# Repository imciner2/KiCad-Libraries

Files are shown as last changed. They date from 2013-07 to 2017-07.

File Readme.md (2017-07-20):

# KiCad Libraries

A library containing Kicad schematic symbols, footprints, and project templates.

- - -
## License

<div align="center"><br /></div>

This library is licensed under the Creative Commons BY-SA 4.0 license. The full legal text of the license may be found in the [License](LICENSE.txt) file in this repository. For more information about this license, please visit the Creative Commons Foundation (http://creativecommons.org/licenses/by-sa/4.0/).

- - -
## Using this library

There are 2 ways to use this library: 

1. Copy files locally into project directory (such as by making a Git Subtree)
2. Make a reference to this git repository inside the project (such as by making a Git Submodule)

Both of these methods are discussed in their respective files:

1. [Git Subtrees](UsingGitSubtree.md)
2. [Git Submodules](UsingGitSubmodule.md)

### 3D Parts

In order to view the 3D parts that accompany the footprints, you must add an environment variable called KISYS3DMOD. If it has not been created, this variable points to the location of the preinstalled 3D models. To use these models and the ones in this repo, simply place both paths in the environment variable.

Note: The path should be to the root of the repository, not the 3D directory.

To add this in Linux (and remove existing models), add these two lines to the .bashrc file

```
# Add an environment variable to add the GitHub KiCad 3D models
export KISYS3DMOD='*path/to/github/directory*'
```

### Templates

In order to use the templates contained in this folder, you must add an environment variable called KICAD_PTEMPLATES. This will create a page in the Kicad template selector for "Portable Templates".

Note: Templates must be specified on the end of the environment variable

To add this in Linux, simply add these two lines to the .bashrc file

```
# Add an environment variable to add the GitHub KiCad templates
export KICAD_PTEMPLATES='*path/to/github/directory*/Templates'
```

## Schematic Library Contents

DataStorage - 
 * SD Card
 * uSD Card

Microprocessors - 
 * Sparkfun Atmega 32U4 Breakout Board
 * Microchip PIC18F27J13
 * Microchip PIC32MX340F512H
 * Texas Instruments MSP430G2553 (20, 28, 32 pin versions)

MiscellaneousDevices - 
 * 74LVC1G374  D-type Latch
 * Bridge Rectifier
 * Split Terminal Capacitor
 * LM2937 Voltage Regulator
 * LM317 Voltage Regulator + Heatsink Pin
 * SPDT Relay
 * 3-switch SPST DIP Switch
 * DPDT Switch
 * DPST Switch
 * SPDT Switch
 * SPST Switch
 * Current Transformer
 * Texas Instruments INA333 Instrumentation Amplifier
 * Texas Instruments TS63061 Buck/Boost regulator
 * AC/DC Dual Rail Convertor
 * AC/DC Single Rail Convertor
 * Linear Regulator (Generic symbol for any 3-pin regulator)
 * 18x2 connector
 * Differential Communications Receiver
 * TI DAC5311 8-bit digital-to-analog converter
 * Analog Devices ADA4805-1 low power/shutdown controller operational amplifier
 * TI LM3481 DC/DC low-side NFET converter controller
 * CubeSat Kit 52-pin dual row header
 * Adafruit Feather Board

RF_OEM_Parts - 
 * RFD900
 * SL1204 GPS Antenna
 * Synapse S200
 * Synapse RF300
 * XBee

Sensors - 
 * Analog Devices ADXL345 3-axis Accelerometer
 * Sparkfun Honeywell HMC6352 3-axis magnetometer breakout
 * InvenSense MPU9150 9-dof IMU
 * SkyTraq Venus638 GPS Receiver
 * Antenova M2M M10382 GPS Receiver
 * Honeywell HIH-5030/5031 Humidity Sensor
 * ST Micro LPS331 Pressure Sensor

TransistorParts - 
 * 3-Terminal (GDS) PMOS
 * 3-Terminal (GDS) NMOS
 * NMOST+PMOS in one package
 * NPN+PNP in one package
 * Dual NMOS in one package
 * NMOS with body diode
 * PMOS with body diode

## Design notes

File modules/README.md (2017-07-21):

# KiCad Libraries - Footprint Modules

This directory contains the footprint modules for this KiCad library. All the footprints in this library are designed to be hand-solderable.

The footprints contained in these libraries follow the standards outlined in the master standards file for the repository: [Standards](../LibraryStandards.md)

# Library Listing

* [Batteries](#batteries)
* [Capacitors](#capacitors)
* [Connectors](#connectors)
* [Digilent](#digilent)
* [Diodes](#diodes)
* [Graphics](#graphics)
* [Inductors](#inductors)
* [LEDs](#leds)
* [Modules](#modules)
* [PTH](#pth)
* [Resistors](#resistors)
* [Sensors](#sensors)
* [SMD](#smd)
* [Solarcells](#solarcells)
* [Switches](#switches)
* [Transistors](#transistors)

Note: DK means the digikey part number.

## Batteries:

Footprints for Various battery holders.
 
| Component | Description | More Information |
| --- | --- | ---|
| BATT_BH2AA-PC | 2 AA Battery Holder, Memory Protection Devices | DK: BH2AA-W-ND |
| BATT_CR2032_MPD | CR2032 Holder, Memory Protection Devices | DK: BC2032-F1-ND |
| BATT_CR2032_TE | CR2032 Holder, Tyco Electronics | DK: A99327CT-ND |
 
## Capacitors:

Footprints for various capacitors.

| Component | Description | More Information |
| --- | --- | ---|
| RADIAL_*lead*_*diam* | Thru-hole Radial Capacitors, lead spacing of *lead*, diameter of *diam* | |
| SMD_POL_*package*_*size* | SMD capacitor, package type is *package*, length/width is *size* | |
 
## Connectors:

Footprints for various connectors.

| Component | Description | More Information |
| --- | --- | ---|
| CONN_2.0mm_1x* | Single row 2mm pitch headers (4 pins per row) | |
| CONN_2.54mm_1x* | Single row 0.1in (2.54mm) pitch headers (1-9 pins per row), friction fit capable (offset holes to hold header in with no solder) | |
| CONN_2.54mm_2x* | Double row 0.1in (2.54mm) pitch headers (2-9, 15, 17 pins per row) | |
| DB9_RT_SLIM | Slim fit DB-9 right angle connector | |
| DC_2.1mm_CUI-PJ-202A | DC Barrel Jack, 2.1mm diameter | DK: PJ-202A-ND |
| DEANS | Fullsize Deans plug connector | [Manufacturer](http://wsdeans.com/products/plugs/ultra_plug.html) |
| DEANS_Micro | Micro Deans plug connector | [Manufacturer](http://wsdeans.com/products/plugs/micro_plug.html) |
| DIN_CUI_SD-50BV | 5 pin DIN connector, vertical | DK: CP-3150-ND |
| DIN_CUI_SDS-50J | 5 pin DIN connector, horizontal | DK: CP-2350-ND |
| GAMING_SNES | SNES controller connector | [Manufacturer](http://www.raphnet-tech.com/products/snes_controller_connector/index.php) |
| JST_2.0mm_1x* | JST 2.0mm pitch connectors | |
| MICRO_SD_HINGE_AMP | Hinged uSD card slot | DK: 101-00303-68-1-ND |
| MOLEX_MINI-FIT-JR_3_PTH_RT_PEG | 3 pin right angle thru-hole Molex Mini-Fit Jr connector | |
| MOLEX_MINI-FIT-JR_3_PTH_VERT | 3 pin vertical thru-hole Molex Mini-Fit Jr connector | |
| SAMTEC_TFM-115-01-F-D-A | Samtec 2x15 (30 position) 0.05in (1.27mm) pitch thru-hole header | DK: SAM8700-ND |
| TESTPOINT_063 | Single testpoint, 0.063in hole diameter | |

## Digilent:

Footprints for the board connector specifications proposed by Digilent inc. (such as the PMOD connector).

| Component | Description |
| --- | --- |
| PMOD_DOUBLE_FEMALE | Double row female PMOD connector (0.1in pitch, 2x6) |
| PMOD_DOUBLE_MALE | Double row male PMOD connector (0.1in pitch, 2x6) |
| PMOD_SINGLE_FEMALE | Single row female PMOD connector (0.1in pitch, 1x6) |
| PMOD_SINGLE_MALE | Single row male PMOD connector (0.1in pitch, 1x6) |

## Diodes:

Footprints for various diode packages.

| Component | Description | More Information |
| --- | --- | ---|
| DIODE_DFN1006 | Leadless diode package (1mm x 0.6mm x 0.48mm body) | |
| DIODE_DO214AB-SMC | SMC size surface mount diode package (8.2mm x 6.3mm x 2.7mm body) | |
| DIODE_SOT23-3 | 3-pin SOT23 diode package (Cathode on pin 3, Anode on pin 1) | |

## Graphics:

Various silkscreen graphics for circuit boards.

| Component | Description |
| --- | --- |
| AXIS_Z-DOWN | Axis indicator for a right-handed system with the Z axis going through the board |
| AXIS_Z-UP | Axis indicator for a right-handed system with the Z axis going up from the board |

## Inductors:

Footprints for various inductors.

| Component | Description | More Information |
| --- | --- | ---|
| IND_BOURNS_SRP1238A | Bourns SRP1238A shielded inductor series | [Manufacturer](http://www.bourns.com/docs/Product-Datasheets/srp1238a.pdf) |

## LEDs:

Footprints specifcally for LEDs.

| Component | Description | More Information |
| --- | --- | ---|
| LED_1206 | 1206 Surface Mount LED (1206 footprint with special 3D model) | |

## Modules:

Footprints for various OEM modules.

| Component | Description | More Information |
| --- | --- | ---|
| ADAFRUIT_FEATHER | Adafruit Feather Board | [Manufacturer](https://www.adafruit.com/feather) |
| ESP-12S | ESP8266 WiFI module with integrated antenna | [Datasheet](https://www.elecrow.com/download/ESP-12S_User_Manual.pdf) |
| PS_CUI_VSK-S20 | CUI VSK-20 AC-DC Power Supply, Thru-hole | [Manufacturer](http://www.cui.com/product/resource/vsk-s20.pdf) |
| PS_RECOM_RAC15 | Recom RAC15 AC-DC Power Supply, Thru-hole | [Manufacturer](https://www.recom-power.com/pdf/Powerline-AC-DC/RAC15-S_D_TA.pdf) |
| SYNAPSE_SM200_SMD | Synapse SNAP wireless module, SM200 | [Manufacturer](http://info.synapse-wireless.com/rf-module-sm200pu1) |
| SYNAPSE_PTH | Synapse SNAP wireless module, thru-hole part | |
| XBEE_PTH | Digi XBee wireless module, thru-hole | |
| XBBE_PRO_PTH | Digi XBee-Pro wireless module, thru-hole | |

## PTH:

Footprints for various thru-hole devices.

| Component | Description | More Information |
| --- | --- | ---|
| TO220_HORIZ | TO-220 Package, horizontal mount with screw mount hole | |

## Resistors:

Footprints for resistors.

| Component | Description | More Information |
| --- | --- | ---|
| RES_D2PACK | D2pack resistor footprint | |

## Sensors:

Footprints for various sensors.

| Component | Description | More Information |
| --- | --- | ---|
| ANTENOVA_M10382 | Antenova M10382 GPS Receiver | [Manufacturer](http://www.antenova-m2m.com/wp-content/uploads/2015/11/M10382_11MD-0043-5-PS.pdf) |
| HONEYWELL_HIH_5030 | Honeywell HIH 5030 Humidity Sensor | [Manufacturer](https://sensing.honeywell.com/index.php?ci_id=49692) |
| SHARP_GP1A57HRJ00F | Sharp GP1A57HRJ00F Photo Interrupter | 425-1935-5-ND |

## SMD:

Footprints for various SMD components not in other libraries.

| Component | Description | More Information |
| --- | --- | ---|
| D2PACK | D2Pack | |
| HC-49SM | HC-49SM crystal | |
| LGA_* | LGA footprints, named using the library naming convention | |
| SMD_0805-SPLIT | 0805 component with a split pad (will br bridged when a component is soldered to it) | |
| SMD_0805_FOURPOST | 0805 component with 4 pads (one on each corner) | Fits the [ATB Baluns](https://product.tdk.com/info/en/documents/data_sheet/rf_balun_atb2012_en.pdf) |
| SMD_0805 | 0805 passive device pad | |
| SMD_1206 | 1206 passive device pad | |
| SMD_2010 | 2010 passive device pad | |
| SOIC_* | SOIC (Small Outline Integrated Circuit) footprints, named using the library naming convention | |
| SON_* | SON (Small Outline No-Lead) footprints, named using the library naming convention | |
| SOT_* | SOT (Small Outline Transistor) footprints (3, 5, 6 pins) | |
| SSOP_* | SSOP (Shrink Small Outline Package) footprints, named using the library naming convention | |

## Solarcells:

Footprints for various solarcells.

| Component | Description | More Information |
| --- | --- | ---|
| SPECTROLAB_CIC_26.62 | Spectrolab CIC cell | [Manufacturer](http://www.spectrolab.com/cic.htm) |
| SPECTROLAB_TASC1 | Spectrolab TASC cell, direction 1 (discontinued) | [Manufacturer](http://www.spectrolab.com/DataSheets/PV/PV_NM_TASC_ITJ.pdf) |
| SPECTROLAB_TASC2 | Spectrolab TASC cell, direction 2 (discontinued) | [Manufacturer](http://www.spectrolab.com/DataSheets/PV/PV_NM_TASC_ITJ.pdf) |

## Switches:

Footprints for various switches.

| Component | Description | More Information |
| --- | --- | ---|
| DIP_3_CK_SDA03H0SBD_SMD | 3 position SMD DIP switch | DK: CKN6060-ND |
| DPDT_ESWITCH_EG2207 | DPDT switch, Eswitch EG2207 | DK: EG1940-ND |
| DPST_TE_SSJ12R04 | DPST switch, TE SSJ12R04 | DK: 450-1635-ND |

## Transistors:

| Component | Description | More Information |
| --- | --- | ---|
| TRANS_SOT-23-3_BEC | 3-pin SOT23 package (Base on pin 1, Emitter on pin 2, Collector on pin 3) | |
| TRANS_SOT-23-3_GSD | 3-pin SOT23 package (Gate on pin 1, Source on pin 2, Drain on pin 3) | |
| TRANS_SO_4.0mm_1.27mm_8 | 8-pin SO package (Gate on pin 4, Source on pins 1-3, Drain on pins 5-8) | |

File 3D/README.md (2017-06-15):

# KiCad Libraries

## Creating 3D Components

To create a new 3D component:

Using OpenSCAD (Based on http://happyrobotlabs.com/posts/tutorials/tutorial-3d-kicad-parts-using-openscad-and-wings3d/):
1) Create the part in OpenSCAD
2) Compile it, then export as a .stl
3) Run meshconv on the file:
    ./meshconv -c stl Path/To/Part-scad.stl -o Path/To/Part-wings
4) Import the new .stl into Wings3D and do the material changing
5) Export as a .wrl file
6) Copy the .wrl file into the 3D folder from its source folder

## 3D Part Models

Batteries:
 * Memory Protection Devices CR2032 Holder (Digikey #: BC2032-F1-ND)

Connectors:
 * 1x6 0.1" female right angle
 * 2x6 0.1" female right angle
 * 1x6 0.1" male right angle
 * 1x6 0.1" male right angle
 * 2.1mm DC Barrel jack (CUI PJ-202A)
 * Deans Plug
 * Micro Deans Plug
 * DIN - Vertical - CUI SD-50BV
 * DIN - Right Angle - CUI SDS-50J 
 * SNES Controller
 * Molex MiniFit Jr 3 pin right angle
 * Samtec 2x15 Thru-hole TFM-115-01-F-D-A
 * uSD card slot - Amphenol (Digikey #: 101-00303-68-1-ND)
 * Testpoint

LEDs:
 * 1206 Surface Mount

Sensors:
 * Sharp GP1A57HRJ00F Photo Interrupter
 * Antenova M2M M10382 GPS Module

SMD:
 * D2PACK
 * 0805
 * 1206
 * 2010
 * HC-49 Surface Mount Crystal
 * No Lead - 3.15mm x 3.15mm x 0.80mm
 * No Lead - 3.00mm x 5.00mm x 1.00mm
 * No Lead - 4.00mm x 4.00mm x 1.00mm
 * No Lead - 10.0mm x 10.0mm x 1.29mm
 * SOIC 8  - 4.0mm x 5.0mm - Pitch: 1.27mm
 * SOIC 8  - 4.0mm x 5.8mm  - Pitch: 1.27mm
 * SOT-23-3
 * SOT-23-5
 * SOT-23-6
 * SOT-363
 * SSOP 8  - 3.0mm x 2.0mm - Pitch: 0.50mm
 * SSOP 8  - 3.0mm x 3.0mm - Pitch: 0.65mm
 * SSOP 20 - 4.5mm x 6.6mm - Pitch: 0.65mm

Solarcells:
 * Solarcells - Spectrolab TASC1
 * Solarcells - Spectrolab TASC2
 * Solarcells - Spectrolab 26.62 sq-cm CIC

Switches:
 * DIP - SMD - 3 position - CK SDA03H0SBD (Digikey #: CKN6060-ND)
 * DPST - Eswitch EG2207 (Digikey #: EG1940-ND)
 * DPST - TE SSJ12R04 (Digikey #: 450-1635-ND)

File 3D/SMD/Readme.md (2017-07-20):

No Lead Packages:

*length*\_*width*\_*height*

SOIC:

*length*\_*width*\_*height*\_P*pitch*

SSOP:

*length*\_*width*\_*height*\_P*pitch*

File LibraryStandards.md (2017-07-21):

# Library Standards

* [Schematic Symbol Standards](#schematic-symbol-standards)
  * [Text](#text)
  * [Pins](#text)
* [Footprint Standards](#footprint-standards)
  * [Pad Design](#pad-design)
  * [Text](#text-1)
  * [Naming Convention](#naming-convention)

----------------------------------------------------------------------------

# Schematic Symbol Standards

## Text

| Text Width | Text Height |
| --- | --- |
| 0.040 in | 0.040 in |

## Pins

The length of a pin should be 0.100 in.

----------------------------------------------------------------------------

# Footprint Standards

## Pad Design

For PTH parts:
* Pad 1 should be a square pad, all others should be round unless required
* Annular ring size should be 1.778mm (0.007in)

## Text

The text fields that should be included on the part are:
* Reference is on Front Silk Screen and is visible, starting value of REF**
* Value is on Front Silk Screen and is invisible, starting value of the footprint name

All text should have the following properties

| Width  | Height | Thickness | 
| --- | --- | --- |
| 1mm | 1mm | 0.2mm |

## Naming Convention

Note: Every field is separated by an underscore.

### Generic Connectors:

| Field | Text |
| ----- | --- |
| 1 | CONN |
| 2 | Pin spacing (in mm) |
| 3 | Number of rows & pins in a row (ie rows x num in rows) |

Example: CONN_2.54mm_1x4

### Specific Connectors:

| Field | Text |
| ----- | --- |
| 1 | Connector Type (optional)  |
| 2 | Manufacturer's Name |
| 3 | Manufacturer's part number |

Example (with type): DC_2.1mm_CUI-PJ-202A

Example (no type)  : SAMTEC_TFM-115-01-F-D-A

### Surface mount components:

| Field | Text |
| ----- | --- |
| 1 | Chip's pacakge label |
| 2 | Total number of pins on the chip |
| 3 | Width of the chip (the plastic casing)  |
| 4 | Length of the chip (the plastic casing) |
| 5 | Pitch of the pins |
| 6 | Additional notation about the package |

Example: SSOP_20_4.5mm_6.6mm_0.65mm_PWP

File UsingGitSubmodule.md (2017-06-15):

# Using Git Submodule to Clone the Library

## Adding to the project (the 1st time)

1. Decide which directory will get the libraries (such as a directory called libraries)

2. Execute the following command (replacing libraries at the end with the desired directory from step 1):

    ``` git submodule add https://github.com/imciner2/KiCad-Libraries libraries ```

3. Interact with the libaries as if it is its own Git repository (aka. pull, commit, push, etc.).

## Updating libraries on fresh clone of KiCad Project

When you first clone a KiCad repository with a submodule of the library, it will not clone the libraries. In order to clone the libraries you must:

1. Initialize the submodules

    ``` git submodule init ```

2. Clone the submodules

    ``` git submodule update ```

This may not always put you on a branch in the server's repository (it may leave you on a floating head branch). To get back to a branch you can make changes to and push to the master, run this inside the submodule:

``` git checkout master ```

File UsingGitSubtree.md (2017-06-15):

# Using Git Subtrees to Clone the Library

## To get the contents of this library into a project git repository

1. Add the remote link:

    ``` git remote add libraries https://github.com/imciner2/KiCad-Libraries.git ```

2. Get the current libraries:

    ``` git fetch libraries ```

3. Initially add the libraries to a project:

    ``` git read-tree --prefix=2-Hardware/libraries -u libraries/master ```

4. Commit the libraries into the repository:

    ``` git commit -m "Kicad libraries initial commit" ```

- - -
## To read in any changes from remote into the project repository:

1. Fetch the libraries repository (if an error occurs running this command, add the remote library again)

    ``` git fetch libraries ```

2. Merge the changes

    ``` git merge -s subtree --squash libraries/master ```

3. Commit the changes

    ``` git commit -m "Updated libraries directory" ```

- - -
## To update the remote with any component changes from this project repository:

1. Create commits for the changes (make them seperate from everything else)

2. Fetch the libraries repository (if an error occurs running this command, add the remote library again)

    ``` git fetch libraries ```

3. Create a new branch locally

    ``` git checkout -b library-work libraries/master ```

4. Add the commits to the desired commits to the new branch (The command shown below will use the 5th commit before the current revision, simply modify the 5 to change which commit is referenced).

    ``` git cherry-pick -x --strategy=subtree master~5 ```

5. Push the changes back to the library master

    ``` git push libraries library-work:master ```

6. Change back to the project repository

    ``` git checkout master ```

7. Delete the working branch

    ``` git branch -D library-work ```

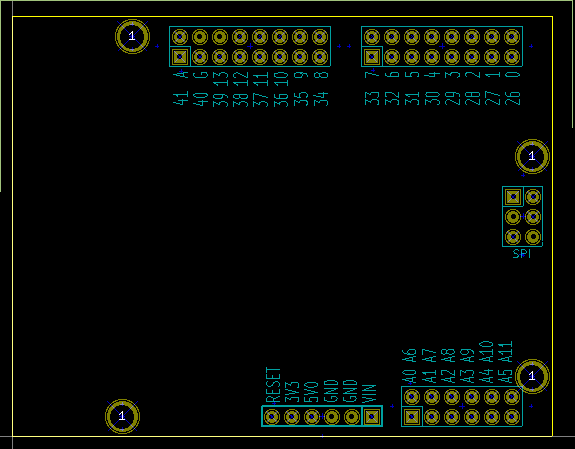
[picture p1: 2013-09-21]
Templates/Chipkit_Shield_uC/meta/board.png

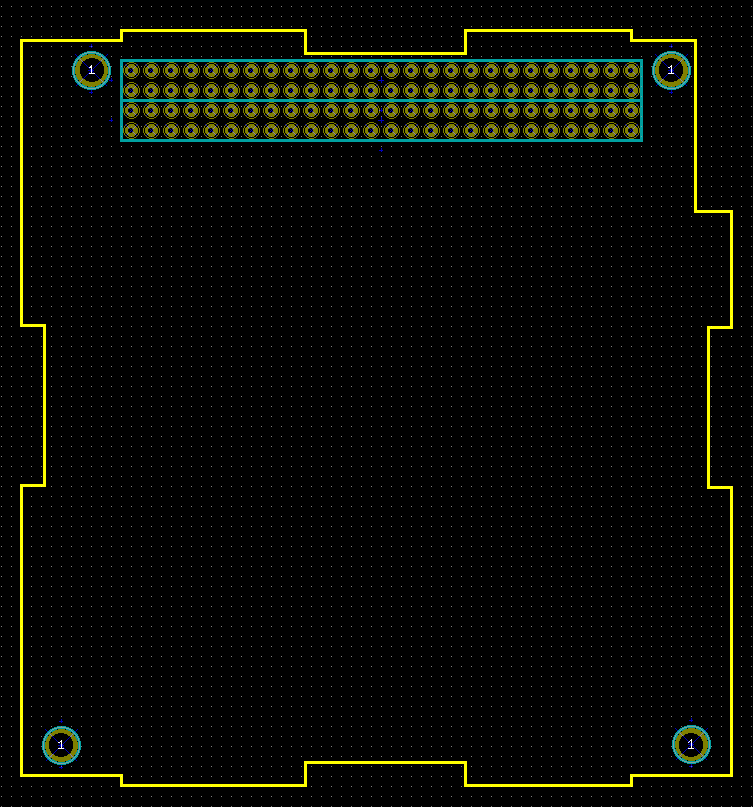
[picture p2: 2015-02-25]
Templates/CubeSatKit_StackBoard/meta/Board.png

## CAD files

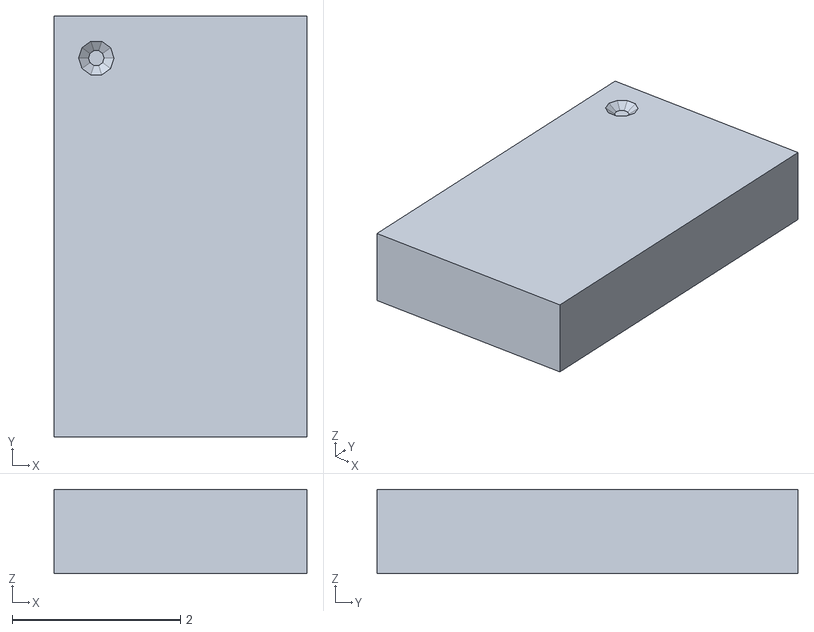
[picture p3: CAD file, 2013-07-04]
3D/0_SourceFiles/ADXL345/ADXL345-SCAD.stl
3.00 x 5.00 x 1.00

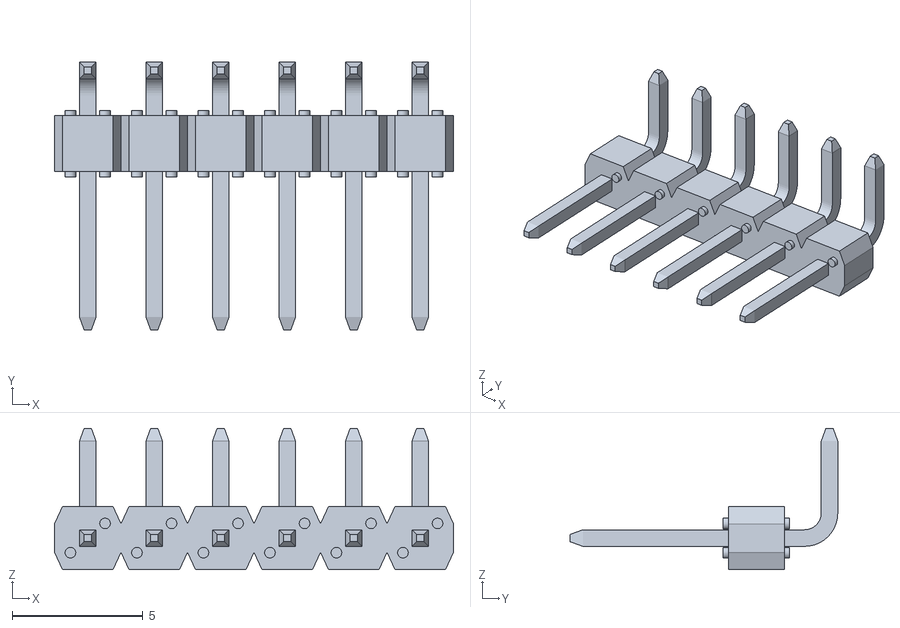
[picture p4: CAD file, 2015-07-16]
3D/0_SourceFiles/Connectors/CONN_1x6/CONN_1x6_Male.stl
15.2 x 10.2 x 5.40

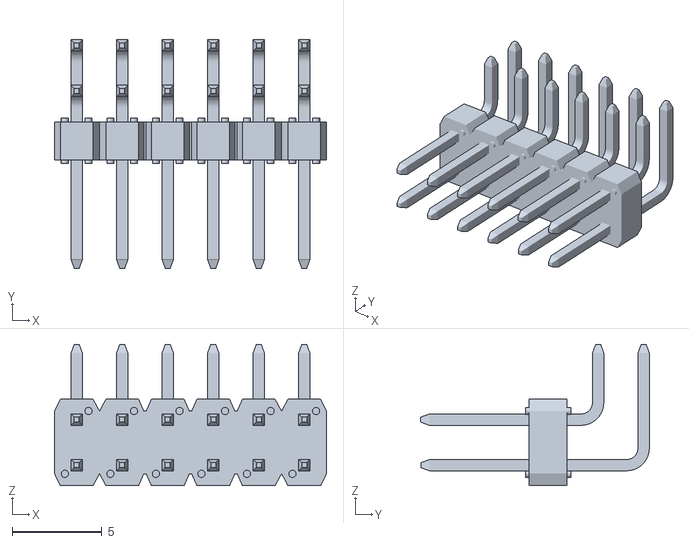
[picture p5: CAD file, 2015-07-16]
3D/0_SourceFiles/Connectors/CONN_2x6/CONN_2x6_Male.stl
15.2 x 12.8 x 7.89

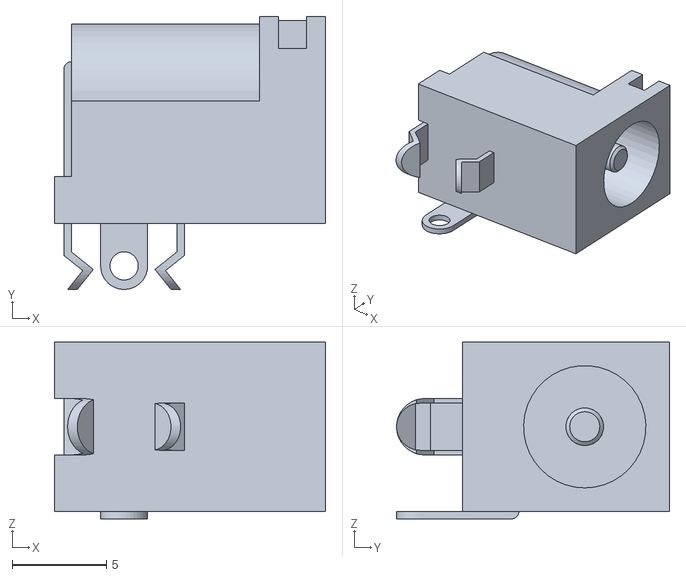
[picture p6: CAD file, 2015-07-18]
3D/0_SourceFiles/Connectors/DC_2.1mm_CUI-PJ-202A/DC_2.1mm_CUI-PJ-202A.stl
14.4 x 14.5 x 9.40

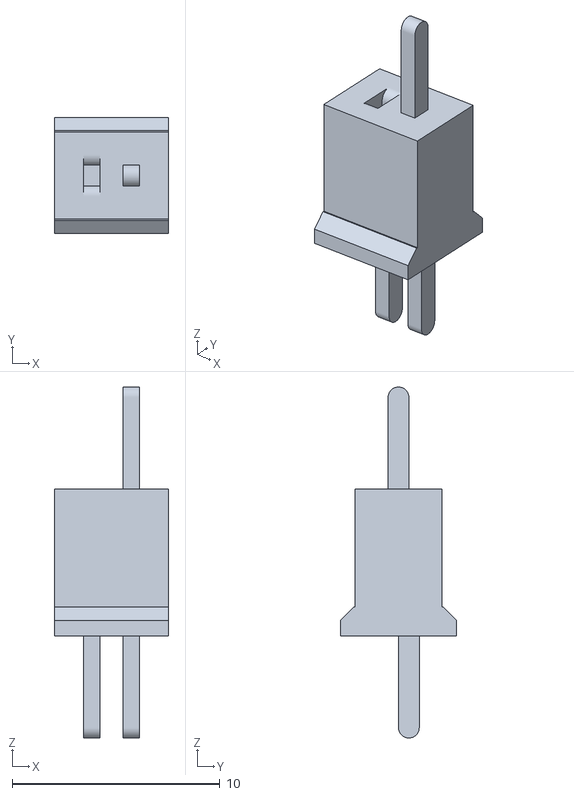
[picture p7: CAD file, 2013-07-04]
3D/0_SourceFiles/Connectors/Deans/DeansMicro-Wings.stl
5.50 x 5.60 x 16.9

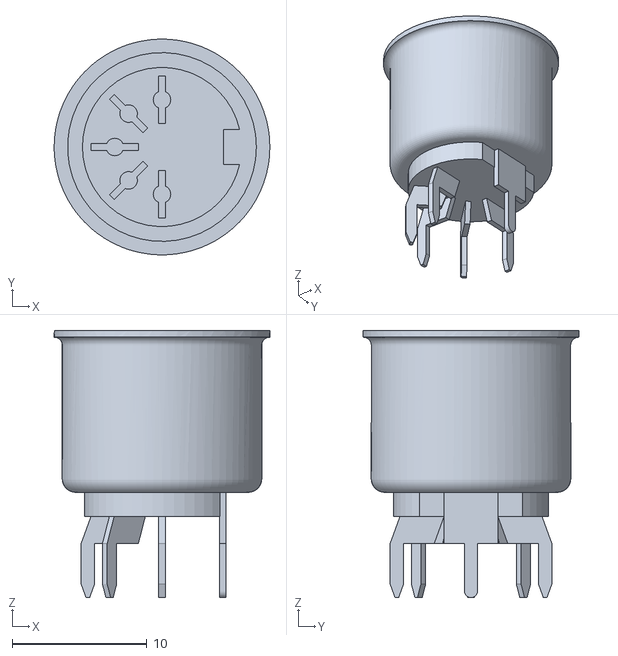
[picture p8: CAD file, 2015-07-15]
3D/0_SourceFiles/Connectors/DIN_CUI_SD-50BV/SD-50BV.stl
16.0 x 16.0 x 19.8

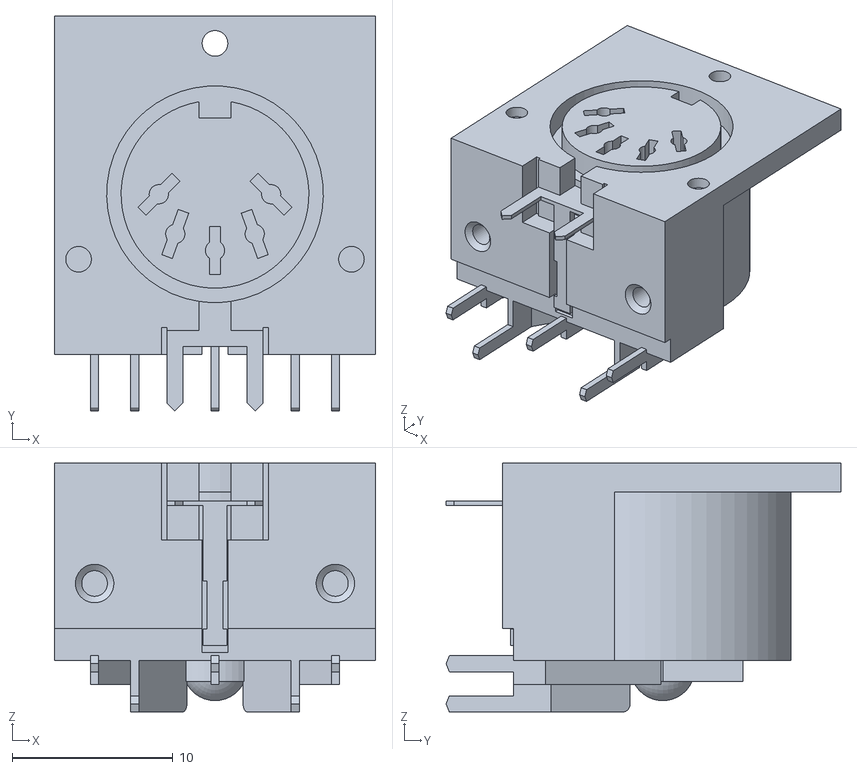
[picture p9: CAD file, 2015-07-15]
3D/0_SourceFiles/Connectors/DIN_CUI_SDS-50J/SDS-50J.stl
20.0 x 24.6 x 15.5

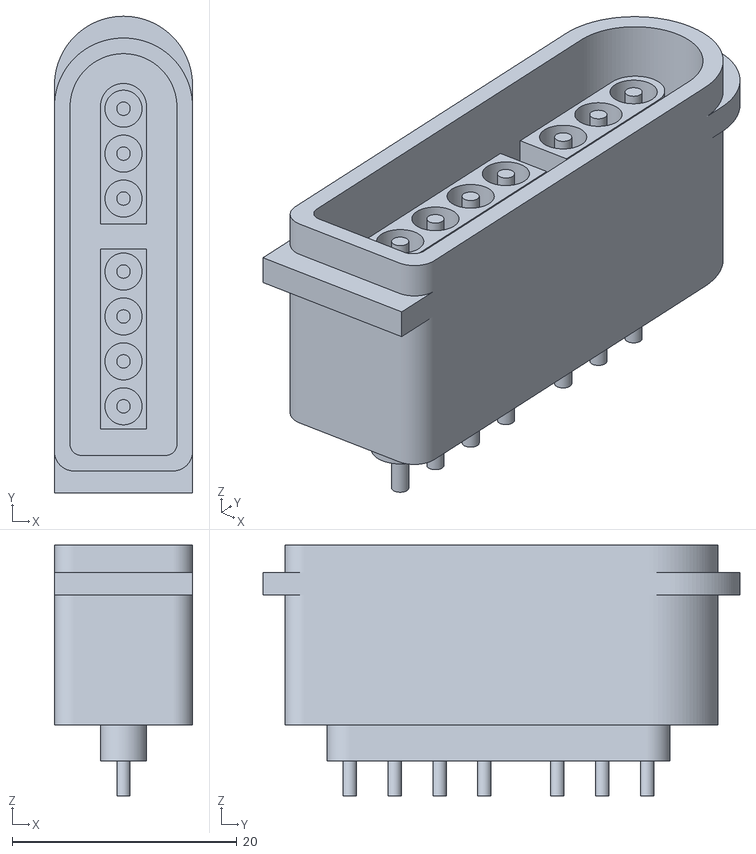
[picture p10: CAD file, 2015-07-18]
3D/0_SourceFiles/Connectors/Gaming_SNES/Gaming_SNES-scad.stl
12.3 x 42.4 x 22.4

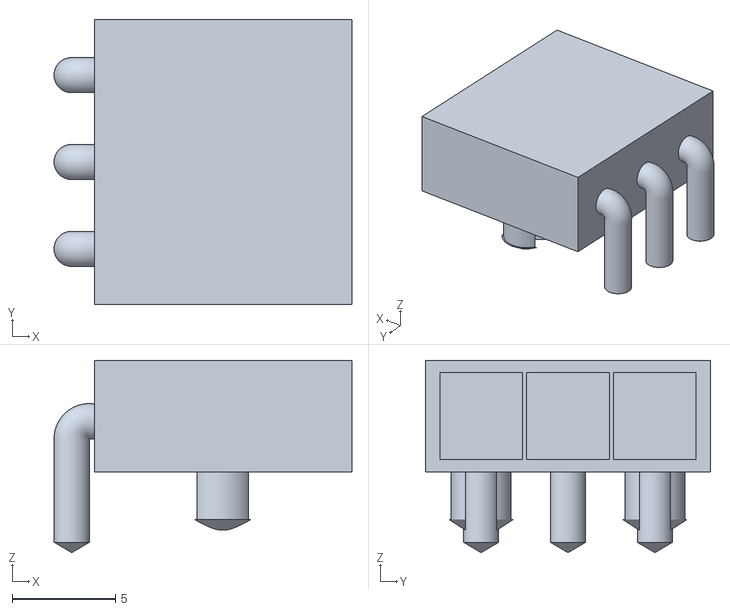
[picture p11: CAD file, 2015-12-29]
3D/0_SourceFiles/Connectors/MOLEX_MINI-FIT-JR_3_PTH_RT_PEG/MOLEX_MINI-FIT-JR_3_PTH_RT_PEG-wings.stl
14.4 x 13.8 x 9.30

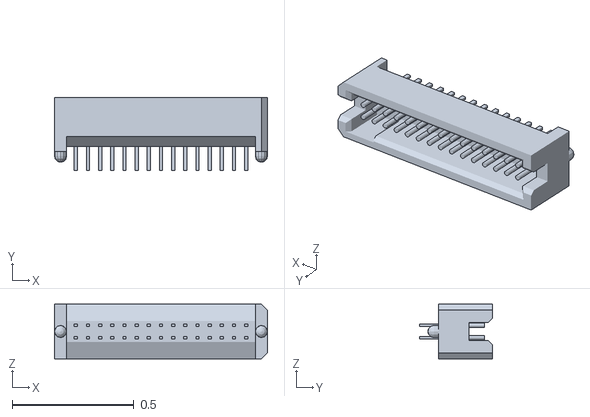
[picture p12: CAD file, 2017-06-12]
3D/0_SourceFiles/Connectors/SAMTEC_TFM-115-01-F-D-A/TFM-115-01-F-D-A.stl
0.875 x 0.298 x 0.225

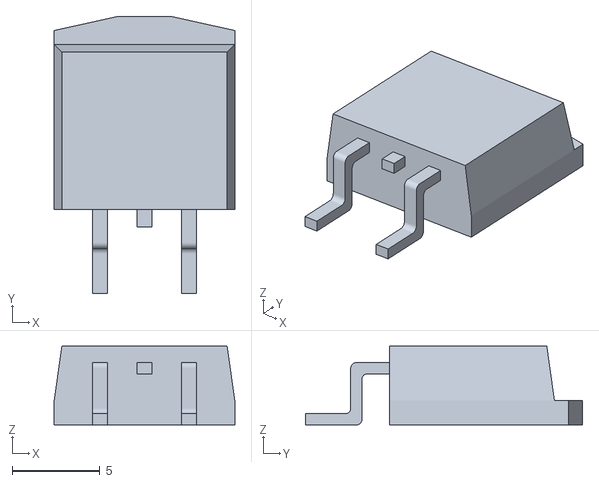
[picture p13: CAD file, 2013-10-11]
3D/0_SourceFiles/D2PACK/D2PACK-Wings.stl
10.3 x 15.8 x 4.50

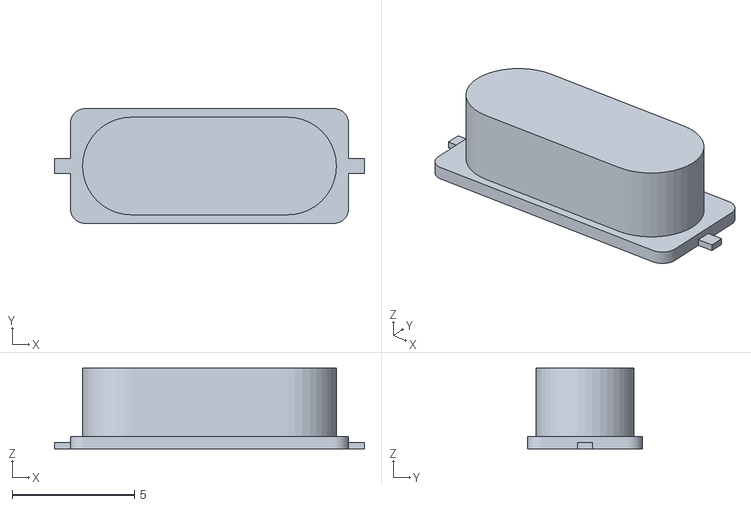
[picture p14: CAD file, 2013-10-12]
3D/0_SourceFiles/HC-49-SMT/HC-49-SMT-scad.stl
12.7 x 4.70 x 3.30

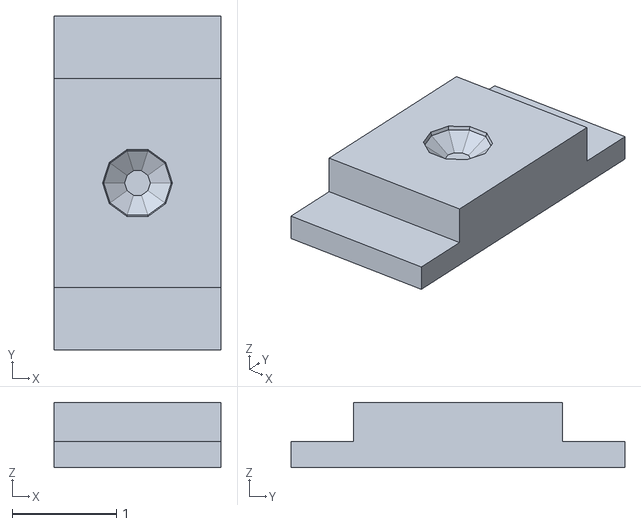
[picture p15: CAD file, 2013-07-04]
3D/0_SourceFiles/LEDs/LED-1206-SCAD.stl
1.60 x 3.20 x 0.625

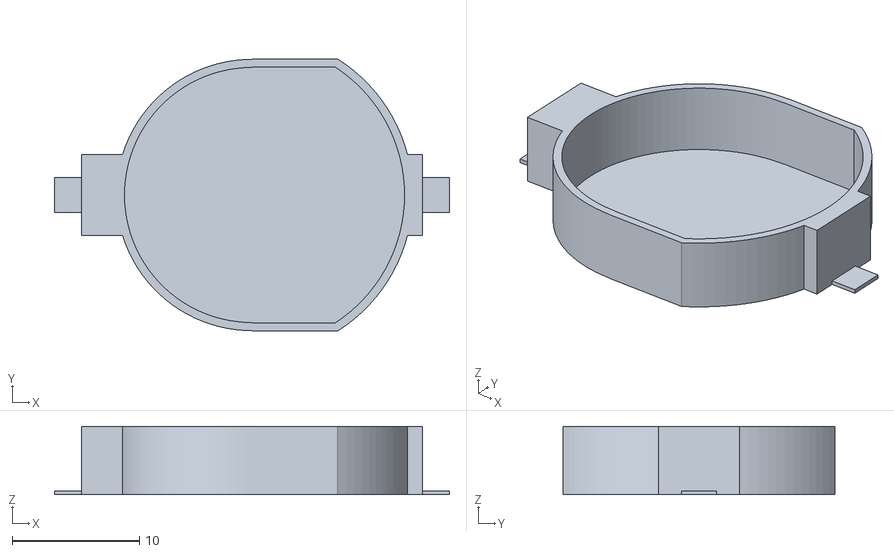
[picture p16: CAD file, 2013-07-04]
3D/0_SourceFiles/MPD_CR2032/MPD_CR2032-SCAD.stl
31.1 x 21.4 x 5.38

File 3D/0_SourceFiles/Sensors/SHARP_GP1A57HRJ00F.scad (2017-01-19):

/*
 * A Sharp GP1A57HRJ00F Photo Interrupter
 *
 */

module pin() {
    translate([0.0, 0.0, -2.0]) cylinder(r=0.45, h=4.0, $fn=100, center=true);
}

module mainBody() {
    difference() {
        cube([18.6, 5, 15.2], center=true);
        translate([0.0, 0.0, 1.6]) cube([10, 6.0, 12.2], center=true);
    }
}

translate([0.0, 0.0, 7.6])mainBody();
translate([0.0, 0.0, -0.35]) cylinder(r=1.5/2, h=0.7, $fn=100, center=true);

translate([7.6, 2.54/2, 0.0]) pin();        // Pin 1
translate([7.6, -2.54/2, 0.0]) pin();       // Pin 2
translate([-7.6, 2.54/2, 0.0]) pin();       // Pin 3
translate([-6.1, 0, 0.0]) pin();            // Pin 4
translate([-7.6, -2.54/2, 0.0]) pin();      // Pin 5

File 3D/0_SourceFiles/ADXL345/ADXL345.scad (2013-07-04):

/*
 * Creates the Analog Devices ADXL345 accelerometer.
 *
 * Author: Ian McInerney
 * Created: June 21, 2013
 */

// Create the chip
difference() {
	// The main chip body
	cube(size=[3.0,5.0,1.0], center=true);

	// The bump to indicate pin 1
	translate([-1.0,2.0,0.70])sphere(r=0.3, center=true, $fn=10);
}

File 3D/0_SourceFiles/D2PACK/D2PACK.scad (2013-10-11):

/*
 * Creates a D2-PACK.
 *
 * Author: Ian McInerney
 * Created: July 8, 2013
 *
 */
use <../Libraries/fillet.scad>

module Pin() {
difference() {
union() {
	translate([0.0,1.45,0.32])cube(size=[0.85,2.9,0.64],center=true);
	translate([0.0,2.9,1.78])rotate([90.0,0.0,0.0])cube(size=[0.85,3.56,0.64],center=true);
	translate([0.0,4.35,3.24])cube([0.85,2.9,0.64],center=true);
	translate([0.0,3.22,2.92])rotate([-90.0,0.0,90.0])fillet(r=0.32,h=0.85);	
	translate([0.0,2.58,0.64])rotate([90.0,0.0,-90.0])fillet(r=0.32,h=0.85);

}
translate([0.0,2.58,3.56])rotate([-90.0,0.0,90.0])fillet(r=0.32,h=0.9);	
translate([0.0,3.22,0.0])rotate([90.0,0.0,-90.0])fillet(r=0.32,h=0.9);
}
}

translate([0.0,5.5,0.0])difference() {
	translate([0.0,0.0,2.25])cube(size=[10.3,11.0,4.5], center=true);

	// The flange on the top
	translate([0.0,4.75,3.0])cube(size=[10.4,1.7,3.2], center=true);
	translate([-5.15,3.9+0.8,-0.1])rotate([0.0,0.0,12.5])cube(size=[5.0,10.0,1.6],center=false);
	translate([5.15,3.9+0.8,-0.1])rotate([0.0,0.0,77.5])cube(size=[5.0,10.0,1.6],center=false);

	// The bevelled sides
	translate([-5.75,3.9,1.4])rotate([8.0,0.0,0.0])cube(size=[11.5,1.0,10],center=false);
	translate([5.15,-5.6,1.4])rotate([0.0,-8.0,0.0])cube(size=[1.0,11.5,10],center=false);
	translate([-5.15,-5.6,1.4])rotate([0.0,8.0,0.0])translate([-1.0,0.0,0.0])cube(size=[1.0,11.5,10],center=false);
}

// The pins (and stub)
translate([-2.54,-4.8,0.0])Pin();
translate([2.54,-4.8,0.0])Pin();
translate([0.0,0.0,3.24])cube(size=[0.85,2.0,0.64],center=true);

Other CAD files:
3D/0_SourceFiles/MPU9150/MPU9150-SCAD.stl
3D/0_SourceFiles/SD_Objects/SD-Amp-microSlot-Wings.stl
3D/0_SourceFiles/Sensors/SHARP_GP1A57HRJ00F-scad.stl
3D/0_SourceFiles/SMD_Passives/SMD-1206-scad.stl
3D/0_SourceFiles/HC-49-SMT/HC-49-SMT.scad
3D/0_SourceFiles/ADXL345/ADXL345-Wings.stl
3D/0_SourceFiles/Connectors/CONN_1x6/CONN_1x6_Female.stl
3D/0_SourceFiles/Connectors/CONN_2x6/CONN_2x6_Female.stl
3D/0_SourceFiles/Connectors/Deans/Deans-SCAD.stl
3D/0_SourceFiles/Connectors/Deans/Deans-Wings.stl
3D/0_SourceFiles/Connectors/Deans/Deans.scad
3D/0_SourceFiles/Connectors/Deans/DeansMicro-SCAD.stl
3D/0_SourceFiles/Connectors/Deans/DeansMicro.scad
3D/0_SourceFiles/Connectors/Gaming_SNES/Gaming_SNES-wings.stl
3D/0_SourceFiles/Connectors/Gaming_SNES/Gaming_SNES.scad
3D/0_SourceFiles/Connectors/MOLEX_MINI-FIT-JR_3_PTH_RT_PEG/MOLEX_MINI-FIT-JR_3_PTH_RT_PEG-scad.stl
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

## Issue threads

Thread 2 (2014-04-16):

Upside-down part: PS_CUI_VSK-S20

imciner2, 2014-04-16:
This part is upside-down. The datasheet actually shows the bottom of the transformer not the PCB footprint. It needs to be flipped so the transformer is on the correct side of the board.

Closed 2017-07-21.

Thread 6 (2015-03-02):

Antennova Footprint Pad Issue

imciner2, 2015-03-02:
The pads on two of the sides do not extend far enough out to make it easy to hand solder. They should be moved to align the center of the pad with the silkscreen line.

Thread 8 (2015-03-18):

Refactor footprints

imciner2, 2015-03-18:
Refactor the old Footprints.mod file into the new *.pretty format.

imciner2, 2015-03-23:
Created new footprints ".pretty" modules for Capacitors, Diodes, Resistors, Connectors, LEDs, and SMD components. Started to merge old footprints into those libraries, more merging must be done so the footprints.mod can be deleted.

imciner2, 2017-07-21:
Completed merge of old footprints into the ".pretty" modules.

Closed 2017-07-21.

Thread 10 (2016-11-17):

Fix PMOD connector pin size

imciner2, 2016-11-17:
Increase hole size in PMOD connector pins to be 0.039in drill size.

Closed 2016-11-18.

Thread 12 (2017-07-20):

Unify Library Standards

imciner2, 2017-07-20:
Create a unified library standards document that contains the footprint and schematic symbol standards (in markup format)

imciner2, 2017-07-20:
Created new file for all the standards.

Closed 2017-07-20.

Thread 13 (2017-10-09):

Fix SSOP_8 Footprint

imciner2, 2017-10-09:
The SSOP_08_3.00mm_2.00mm_0.5mm footprint is too wide. The pads do not line up with the pins (the pins of the package start at the inner edge of the pads).

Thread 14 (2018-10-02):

Fix drill size on 0.1" headers

imciner2, 2018-10-02:
Fix the drill size for all the 0.1" connectors to be 0.040".

Closed 2018-10-02.

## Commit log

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2013-05-28 Added to Microprocessors.lib: * PIC32MX340F512H Added to RF_OEM_Parts.lib: * RFD900 * SL1204 Added to Sensors.lib: * MPU9150 * Venus 638
2013-06-13 Added to: MiscellaneousDevices.lib * 3-pin DIP Switch symbol
2013-07-04 Added Readme.txt listing all components Added Footprints.mod containing the PCBnew footprints Added various 3D modles of components
    [ADXL345-SCAD.stl, ADXL345-Wings.stl, ADXL345.scad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]
2013-09-21 Added the Chipkit uC32 shield project template.
    [Chipkit_Shield_uC.kicad_pcb, Chipkit_Shield_uC.sch]
2013-10-11 Changed pin sizes to be smaller. Added new components.
2013-10-11 Added D2PACK 3D models.
    [D2PACK-SCAD.stl, D2PACK-Wings.stl, D2PACK.scad]
2013-10-11 Seperated uSD and SD card out and changed the symbol reference. Added D2PACK footprint.
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2013-10-12 Added footprints and 3D for the M10382 GPS and the SON-10 package.
    [M10382_GPS-scad.stl, M10382_GPS-wings.stl, M10382_GPS.scad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]
2013-10-12 Added a footprint for an HC-49 surface mount crystal
    [HC-49-SMT-scad.stl, HC-49-SMT-wings.stl, HC-49-SMT.scad]
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2013-12-22 Added Spectrolab CIC 3D Model.
    [Spectrolab_CIC-SCAD.stl, Spectrolab_CIC-Wings.stl.stl, Spectrolab_CIC.scad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]
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2014-02-06 Added symbols for single and dual rail power supplies.
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2014-02-08 Added slim DB9 connector and 2x17 0.1in header
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2014-02-08 Fixed pin problem on CONN_2x17.
2014-04-16 Fixed Molex Mini-Fit Jr. board lock holes.
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2014-08-10 Initial Max32 template. It is not finished yet.
    [Chipkit_Shield_Max32.kicad_pcb, Chipkit_Shield_Max32.sch]
2015-02-25 CubeSat Kit board template
    [CubeSatKit_StackBoard.kicad_pcb, CubeSatKit_StackBoard.sch]
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2015-03-23 Parts for 0805, 1206, 2010 passives
    [SMD-0805-scad.stl, SMD-0805-wings.stl, SMD-0805.scad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]
2015-07-14 Added PMOD schematic symbols
    (cherry picked from commit 4b627fcd938dd52d8477768d83b2dc57bcbcf498)
2015-07-14 Added NPN and PNP schematic symbols
    (cherry picked from commit 45c236200b64f831576a3ccd99dd5200a116bce0)
2015-07-14 Added TI charge pump devices
    (cherry picked from commit b78165f6f4d6c99737d7e4b7d2c48ab49af8acd9)
2015-07-15 3D models for a DIN connector and a testpoint
2015-07-15 Added connector 3D source files
    [Deans-SCAD.stl, Deans-Wings.stl, Deans.scad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]
2015-07-15 Fixed issue with diode footprint file
    (cherry picked from commit a878b3ac0e1ee05c4aa9666171c1e14ce12f3403)
2015-07-15 PMOD-Compatible connector footprints
    (cherry picked from commit 5eb52a478ae3523675ae5ffe1071d939003c7fd1)
2015-07-15 Footprint for a CUI SDS-50J DIN Connector
    (cherry picked from commit 28804abba6fccceab47350681357b8cfee6dc547)
2015-07-15 Footprint for a testpoint
    (cherry picked from commit 2105504bfb596bb06abee75cc037e92d2193b44d)
2015-07-16 Single row 1x6 headers
    [CONN_1x6_Female.stl, CONN_1x6_Male.stl]
2015-07-16 Double row 1x6 headers
    [CONN_2x6_Female.stl, CONN_2x6_Male.stl]
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2015-07-16 Added 3D models for DIN connectors
    (cherry picked from commit 720bcfb476b5d6f80964b98119d94342ad5b68d7)
2015-07-16 3D files for SOT-23 packages
    [SOT-23-6-scad.stl, SOT-23-6-wings.stl, SOT-23-6.scad]
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2015-07-16 3D files for SOIC 8 packages
    [SO_08_4.0mm_5.0mm_1.27mm-scad.stl, SO_08_4.0mm_5.0mm_1.27mm-wings.stl, SO_08_4.0mm_5.0mm_1.27mm.scad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]
2015-07-16 Renamed SO components to SOIC
    [SOIC_08_4.0mm_5.0mm_1.27mm-scad.stl, SOIC_08_4.0mm_5.0mm_1.27mm-wings.stl, SOIC_08_4.0mm_5.0mm_1.27mm.scad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]
2015-07-16 Added SSOP 8 and 20 pin 3D models
    [SSOP_08_3.0mm_3.0mm_0.65mm-scad.stl, SSOP_08_3.0mm_3.0mm_0.65mm-wings.stl, SSOP_08_3.0mm_3.0mm_0.65mm.scad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]
2015-07-17 Fixed pin numbering issue
    (cherry picked from commit abdb76b53385136e9d1f587c5b24c18b970a6c0f)
2015-07-18 2.1mm DC Jack footprint
    [DC_2.1mm_CUI-PJ-202A.stl]
2015-07-18 Created SNES connector model and footprint
    [Gaming_SNES-scad.stl, Gaming_SNES-wings.stl, Gaming_SNES.scad]
2015-07-18 Moved all schematic symbols into their own directory
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2015-12-27 Added miscellaneous connectors
    (cherry picked from commit dbb821e3c2c8de55b52db9e2564831a8fb8237b4)
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2015-12-29 Right-angle Molex mini-fit Jr connector
    [MOLEX_MINI-FIT-JR_3_PTH_RT_PEG-scad.stl, MOLEX_MINI-FIT-JR_3_PTH_RT_PEG-wings.stl, MOLEX_MINI-FIT-JR_3_PTH_RT_PEG.scad]
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2016-11-18 Changed hole size, fixes #10
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2017-01-19 Footpring and 3D model for Sharp photo interrupter
    [SHARP_GP1A57HRJ00F-scad.stl, SHARP_GP1A57HRJ00F-wings.stl, SHARP_GP1A57HRJ00F.scad]
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2017-01-23 New SSOP 8 footprint
    [SSOP_08_3.0mm_2.0mm_0.5mm-scad.stl, SSOP_08_3.0mm_2.0mm_0.5mm-wings.stl, SSOP_08_3.0mm_2.0mm_0.5mm.scad]
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2017-06-12 Added Samtec TFM connector
    [TFM-115-01-F-D-A-wings.stl, TFM-115-01-F-D-A.stl]
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2017-06-15 Refactored 3D and updated readme
    [ADXL345-SCAD.stl, ADXL345-Wings.stl, ADXL345.scad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]
2017-07-20 Schematic and footprint for the ESP-12S
    This module is a pre-made module for the ESP8266 WiFi chip.
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2017-07-20 Updated master readme
    - Removed PCB footprint listing
    - Added links to discussed files
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2017-07-21 Updated CubeSat template
    [CubeSatKit_StackBoard.kicad_pcb, CubeSatKit_StackBoard.sch]
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2017-10-10 BOM: Modified BOM scrtip
    This BOM script will sort the components by value and create a CSV.
2018-10-02 Modified connectors
    * Renamed all connectors to remove row count (only pin count left)
    * Added 40 pin connector
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2018-10-02 Fixed hole diameters
    Fixes #14
2018-10-03 Fixed connector descriptions
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2018-10-18 Fixed drawings layer
    Added a line to designate where the PMOD connectors should touch when spacing multiple on a board.
